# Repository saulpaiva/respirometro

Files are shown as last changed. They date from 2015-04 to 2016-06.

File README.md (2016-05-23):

# **RESPIRÔMETRO**
[Centro de Tecnologia Acadêmica - UFRGS](http://cta.if.ufrgs.br)

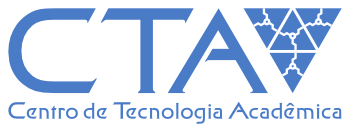
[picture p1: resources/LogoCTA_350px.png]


**Autor/es:** Béuren Felipe Bechlin

**Licença/s:** GPL v3

---
## Descriçao do projeto

O Respirômetro é um equipamento desenhado para medir a frequência respiratória humana. 
Utilizando um par de termistores, o sinal analógico da respiração é convertido em sinal 
digital que pode então ser processado por um microcontrolador que envia dados para o computador.

---
## Primeiros passos

Para utilização do projeto é necessário uma placa de prototipagem Arduino ou um microcontrolador
ATMEGA com suporte a wiring. Na pasta sources você irá encontrar a pasta Arduino que contém o código
fonte deve estar no microcontrolador, já na pasta python contém os códigos fontes para coleta de dados
que são enviados ao computador via comunicação serial gerando um arquivo de log. Nessa mesma pasta
se encontra o arquivo para análise dos dados que foram salvas com a etapa anterior. Lembrando que os
códigos foram desenvolvidos usando *Python* e para seu funcionando é necessário ter instalado o 
interpretador *Python*.
 
### Usando o projeto

#### Passo 1
Primeiro passo a se realizar é instalar as dependências do projeto em sua máquina, caso utiliza
um sistema operacional baseado em GNU/Linux esse trabalho foi reduzido. Supondo que você está
em um ambiente Linux use o seguinte comando:

Esse passo você irá realizar somente uma vez, como é necessário instalar pacotes e módulos python
em seu computador será necessário a senha de administrador para essas operações.

``` Unix
make setup 
```

Após realizar este comando reinicie seu terminal e então realize o segundo passo.

#### Passo 2
Nessa parte será enviado o software para a placa microcontroladora para isso estamos usando
o framework Platformio, lembrando que o firmware desenvolvido foi feito para microcontroladores
ATMEL como suporte a wiring, como por exemplo Arduinos em geral.

``` Unix
make firmware
```

Ao entrar com esse comando irá se iniciar uma tela para seleção da placa que se está usando, além
da porta usb em que ela está conectada ao computador. Na primeira vez que for enviar o firmaware para
cada tipo de placa será necessário digiar _y_ no terminal para que o platformio instale as dependências
para compilação de cada modelo de placa.

---
Para demais informações e documentação completa visite
[CTA - RESPIRÔMETRO](http://cta.if.ufrgs.br/projects/fisiolog/wiki/Respirômetro)

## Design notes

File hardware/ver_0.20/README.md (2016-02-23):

# Respirômetro

Documentação referente a placa de circuito impresso versão 0.2.
Versão em dosenvolvimento.

### Resitores(ohm):
* R1 (6) = 7.3k 
* R2 (4) = 10k
* R3 (2) = 100k
* R4 (2) = 2.2k
* R5 (0) = 3.3k (SD shield)
* R6 (0) = 1.8k (SD shield)
* R7 (3) = 220

### Capacitores:
* C1 (2) = 100 uF 16v

### Cartão SD:

Começando por cima chip conectando para a esquerda, ou o NC(não conectado).

1. NC
2. CS/SS
3. MOSI	= 11 Pin
4. GND
5. NC
6. 3.3v
7. SCK/CLK	= 13 Pin
8. GND
9. MISO 	= 12 Pin
10. NC
11. NC

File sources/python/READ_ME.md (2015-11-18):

# **Respirômetro**

[Centro de Tecnologia Acadêmica - UFRGS](http://cta.if.ufrgs.br)

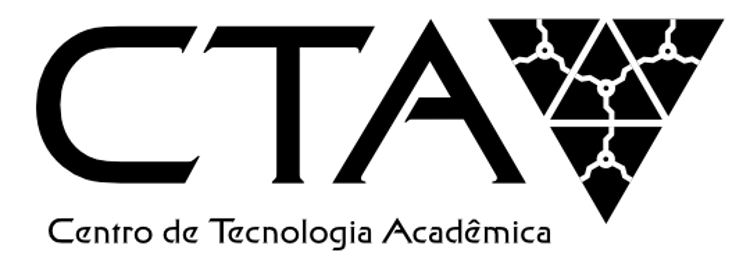
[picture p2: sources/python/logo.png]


**Autor:** Béuren F. Bechlin

**Licença:** GPL v3

---

## Descrição do projeto

O projeto visa criar um equipamento open source que procura inferir a frequência
respirátoria de um indíviduo de forma não invasiva, dimunuindo incômodo como
também possibilitando maiores formas. 

---

## Documentação de uso

### Arduino

 Inicialmente é necessário fazer upload do sketch biometrica.ino para seu micro-
controlador arduino.

### Python

Para o perfeito funcionamento dos algoritmos é necessário ter um interpretador
de python com pelo menos a versão 2.7 instalada em sua máquina. Além disso,
alguns módulos de python são necessários:

* python-scipy
* python-tk (tkInter)
* python-matplotlib
* python-serial

```
sudo apt-get install python-scipy python-tk python-matplotlib python-serial 
```

#### Armazenamento.py

Programa para aquisição dos dados do Arduino salvando-os em um arquivo .log.

Este programa é utilizado com o programa biometrica.ino no qual a taxa de
amostragem é definida no microcontrolador.

Ordem de argumentos : [porta],[taxa_transmissão],[arquivo_saída]
Onde:
1. porta: porta serial no qual o arduino está conectado
2. taxa_transmissão: velocidade de comunicação serial
3. arquivo_saída: nome do arquivo em que os dados serão salvos
4. tempo_de_execução: tempo total de execução, em segundos

PADRÃO NOME DO ARQUIVO DE SAÍDA: coleta_[Nome]_[Sobrenome]_[obs].log
[obs] são observações caso sejam necessárias

Lembrando também que a taxa de transmissão(Baud Rate) da comunicação serial tem
de ser multiplo par de 300. Exemplo 1200, 9600.

#### Visualiza.py

Programa que estima e emite um relatório sobre a frequência respiratória. Lembrando
que quanto menor o tempo amostrado maior a imprecisão do método. Além disso, o tempo
mínimo de amostragem é 5s.

Ordem de argumentos : [arquivo_entrada], [instante inicial], [instante final],
[tipo do filtro], [repetições], [freq_inicial], [freq_final]

Onde:

1. Evidenciando arquivo onde estão os dados a serem anilizado/exibidos:
	1. arquivo_entrada: arquivo que será visualizado/analisado.

2. Determinando em que ponto da amostra quer ser analizado:
	1. instante inicial(s): instante para iniciar a visualização/analise.
	2. instante final(s): instante para finalizar a visualização/analise.

3. Escolhendo filtro apropriado:
	1. tipo do filtro: escolher o filtro a ser utilizado no processo. (1 ou 2)
	2. repetições: definir a quantidade de vezes que o filtro será utilizado.

4. Definindo o espectro de frequência a se uso:
	1. freq_inicial(Hz): definir a frequência inicial positiva que será usada, isso
influenciará na precisão do resultado para o método.
	2. freq_final(Hz): definir a frequência final positiva que será usada, lembrando
que pela definição de transformada de fourier o domínio do espectro de frequência
não será maior que a frequência de obtenção desses dados divido por 2, ou seja,
a as frequências definidas aqui devem estar no intervalo [0;freq/2].

--- 
Para demais informações e documentação completa visite
[CTA - RESPIRÔMETRO](http://cta.if.ufrgs.br/projects/fisiolog/wiki/Respir%C3%B4metro)

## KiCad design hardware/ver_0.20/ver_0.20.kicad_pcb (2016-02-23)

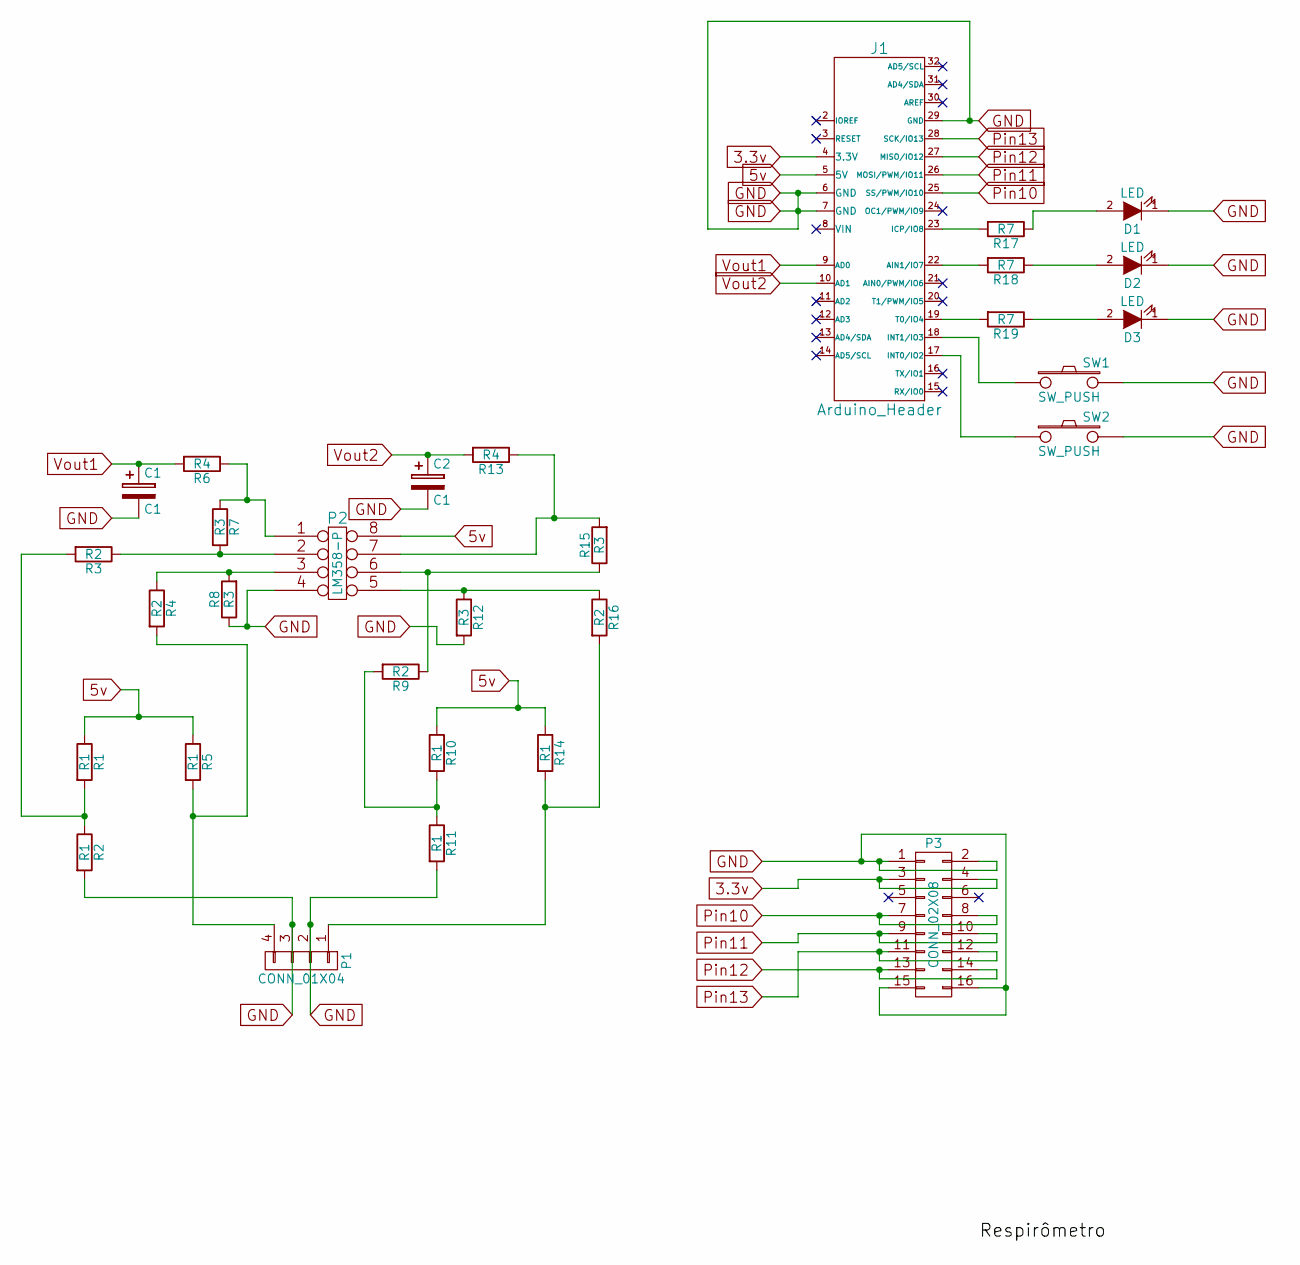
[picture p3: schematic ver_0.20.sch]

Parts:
C1, C2: C1; C2V8
D1, D2, D3: LED; LED-5MM
J1: Arduino_Header; arduino_header
P1: CONN_01X04; Socket_Strip_Straight_1x04
P2: LM358-P; DIP-8_W7.62mm_LongPads
P3: CONN_02X08; Socket_Strip_Straight_2x08
R1, R2, R5, R10, R11, R14: R1; Resistor_Horizontal_RM10mm
R3, R4, R9, R16: R2; Resistor_Horizontal_RM10mm
R6, R13: R4; Resistor_Horizontal_RM10mm
R7, R8, R12, R15: R3; Resistor_Horizontal_RM10mm
R17, R18, R19: R7; Resistor_Horizontal_RM10mm
SW1, SW2: SW_PUSH; SW_PUSH_SMALL

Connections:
3.3v: J1.4 (3.3V), P3.3, P3.4
5v: J1.5 (5V), P2.8, R1.1, R5.1, R10.1, R14.1
GND: C1.2, C2.2, D1.1 (K), D2.1 (K), D3.1 (K), J1.6 (GND), J1.7 (GND), J1.29 (GND), P1.2, P1.3, P2.4, P3.1, P3.2, P3.15, P3.16, R2.2, R8.1, R11.2, R12.2, SW1.2, SW2.2
unnamed: D1.2 (A), R17.1
unnamed: D2.2 (A), R18.1
unnamed: D3.2 (A), R19.1
unnamed: J1.17 (INT0/IO2), SW2.1
unnamed: J1.18 (INT1/IO3), SW1.1
unnamed: J1.19 (T0/IO4), R19.2
unnamed: J1.22 (AIN1/IO7), R18.2
unnamed: J1.23 (ICP/IO8), R17.2
unnamed: P1.1, R14.2, R16.2
unnamed: P1.4, R4.2, R5.2
unnamed: P2.1, R6.1, R7.1
unnamed: P2.2, R3.1, R7.2
unnamed: P2.3, R4.1, R8.2
unnamed: P2.5, R12.1, R16.1
unnamed: P2.6, R9.1, R15.1
unnamed: P2.7, R13.1, R15.2
unnamed: R1.2, R2.1, R3.2
unnamed: R9.2, R10.2, R11.1
Pin10: J1.25 (SS/PWM/IO10), P3.7, P3.8
Pin11: J1.26 (MOSI/PWM/IO11), P3.9, P3.10
Pin12: J1.27 (MISO/IO12), P3.13, P3.14
Pin13: J1.28 (SCK/IO13), P3.11, P3.12
Vout1: C1.1, J1.9 (AD0), R6.2
Vout2: C2.1, J1.10 (AD1), R13.2

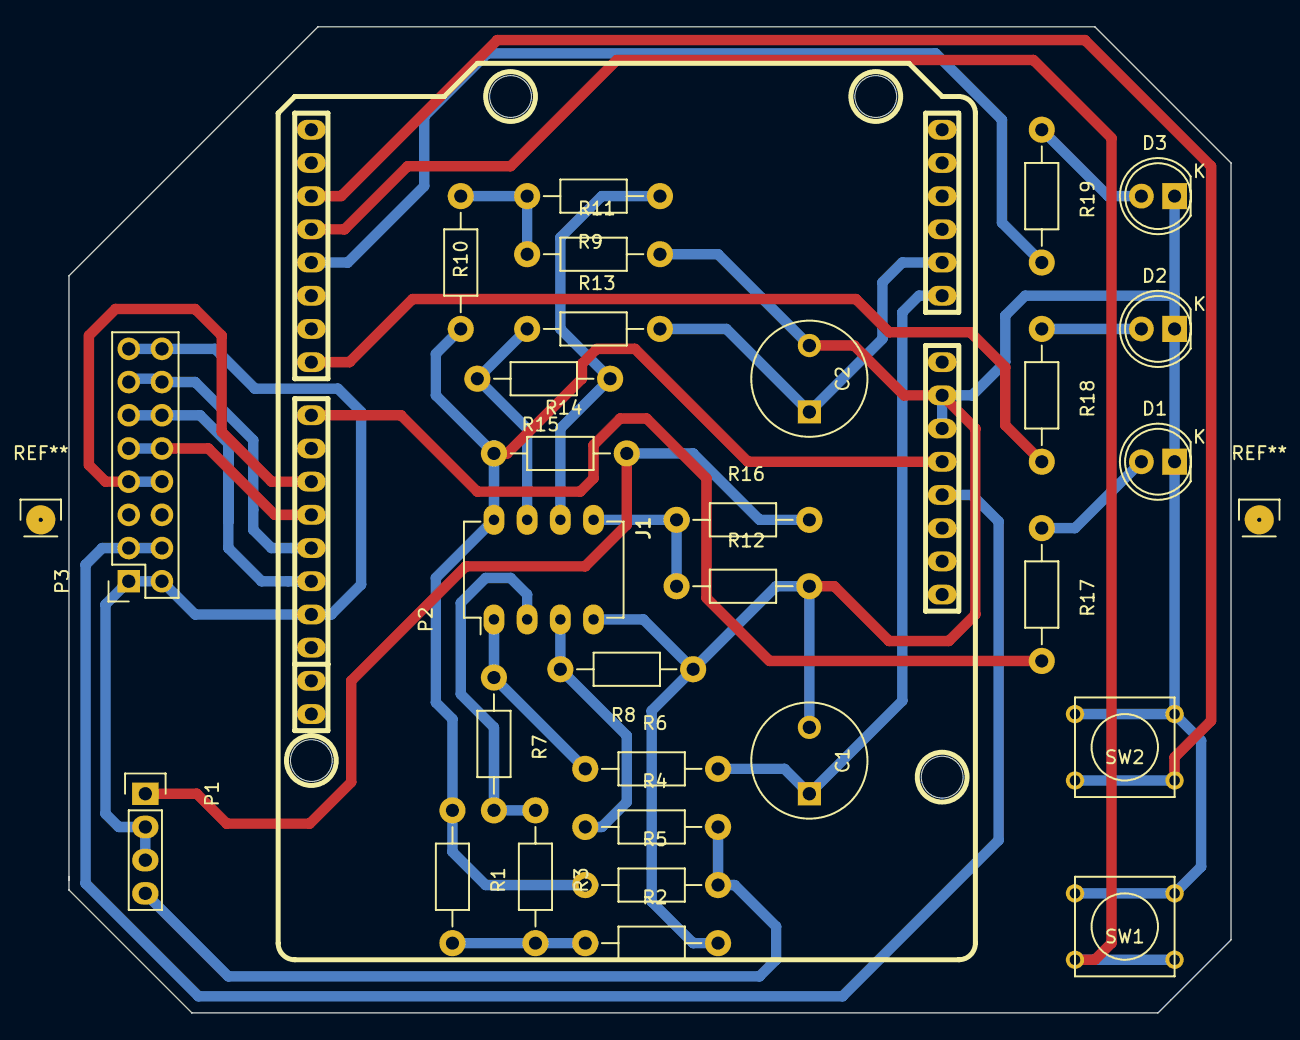
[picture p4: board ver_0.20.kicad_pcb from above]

Board: 2 copper layers, 88.9 x 75.4 mm, 30 parts (0 on the bottom side), 27 nets.

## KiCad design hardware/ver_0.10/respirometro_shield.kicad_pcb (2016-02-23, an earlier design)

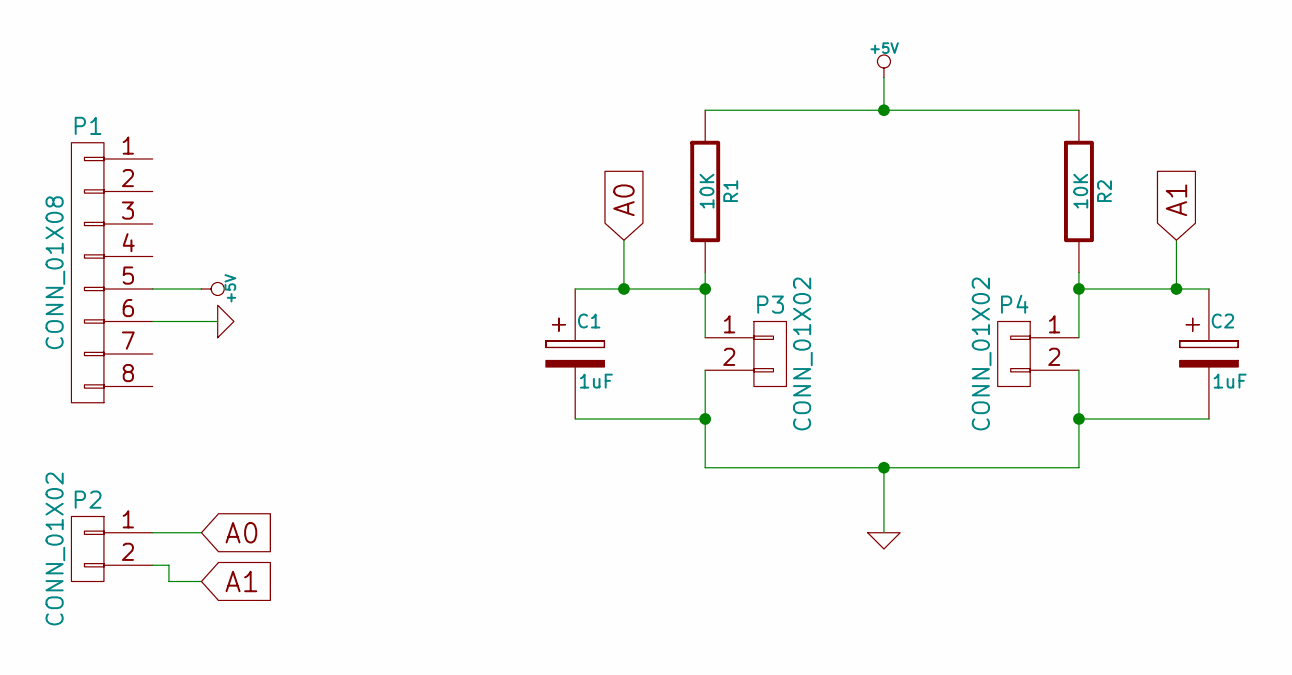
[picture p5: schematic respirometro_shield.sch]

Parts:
C1, C2: 1uF; C_Radial_D5_L11_P2.5
P1: CONN_01X08; PINHEAD1-6
P2, P3, P4: CONN_01X02; PINHEAD1-2
R1: 10K; Resistor_Horizontal_RM10mm
R2: 10K; Resistor_Horizontal_RM15mm

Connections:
+5V: P1.5, R1.1, R2.1
A0: C1.1, P2.1, P3.1, R1.2
A1: C2.1, P2.2, P4.1, R2.2
GND: C1.2, C2.2, P1.6, P3.2, P4.2

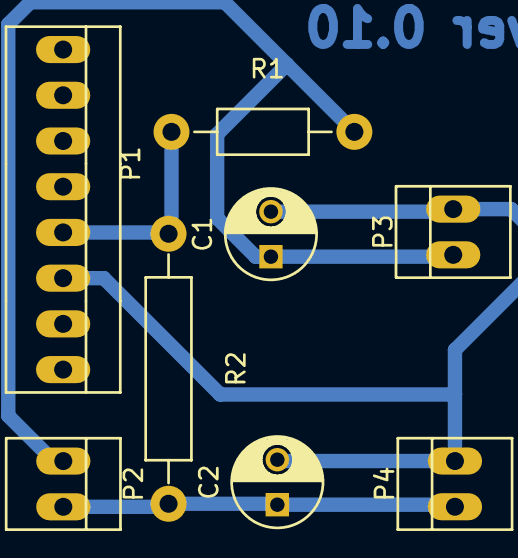
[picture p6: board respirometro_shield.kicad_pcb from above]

Board: 2 copper layers, 8 parts (0 on the bottom side), 4 nets.

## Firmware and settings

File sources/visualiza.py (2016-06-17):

#!/usr/bin/env python
# -*- coding: utf-8 -*-
'''
 Estação biométrica CTA
 Béuren Bechlin

 Programa para estimar a frequência respiratória

 Centro de Tecnologia Acadêmica - UFRGS
 http://cta.if.ufrgs.br

 Licença: GPL v3
 Ordem de argumentos : [arquivo_entrada], [instante inicial], [instante final],
    [tipo do filtro], [repetições], [freq_inicial], [freq_final]
 Onde:

  -Evidenciando arquivo onde estão os dados a serem anilizado/exibidos:
	[arquivo_entrada]: arquivo que será visualizado/analisado.

  -Determinando em que ponto da amostra quer ser analizado:
    [instante inicial](s): instante para iniciar a visualização/analise.
	[instante final](s): instante para finalizar a visualização/analise.

  -Escolhendo filtro apropriado:
    [tipo do filtro]: escolher o filtro a ser utilizado no processo. (1 ou 2)
	[repetições]: definir a quantidade de vezes que o filtro será utilizado.

  -Definindo o espectro de frequência a se uso:
    [freq_inicial](Hz): definir a frequência inicial positiva que será usada, isso
        influenciará na precisão do resultado para o método.
    [freq_final](Hz): definir a frequência final positiva que será usada, lembrando
        que pela definição de transformada de fourier o domínio do espectro de
        frequência não será maior que a frequência de obtenção desses dados
        divido por 2, ou seja, a as frequências definidas aqui devem estar no
        intervalo [0;freq/2]
'''
# Exemplo: python3 visualiza.py coleta_Nome_Exemplo_1min.log 0 60 2 4 0 1
from array import *
from scipy.fftpack import fft, fftfreq, fftshift
import numpy as np
from armazenamento import unpackData, selectDataRange
import sys, os, re, math
import matplotlib.pyplot as plt

# ERROS:
# Testando se contém os argumentos
if len(sys.argv) < 8:
    sys.stderr.write('ERRO: Argumentos insuficientes.\nEm caso de dúvidas leia o READ_ME.md.\n' )
    sys.exit(1)
# Arquivo de dados existe
if not os.path.exists(sys.argv[1]):
	sys.stderr.write('ERRO: Arquivo '+sys.argv[1]+' não encontrado!\nEm caso de dúvidas leia o READ_ME.md.\n')
	sys.exit(1)

# Atribuindo as váriaveis com os valores de entrada
parametro = sys.argv[1:]
log_file = parametro[0]
t_inicial = int(parametro[1])
t_final = int(parametro[2])
n_filtro = int(parametro[3])
qtd_filtro = int(parametro[4])
freq_i = float(parametro[5])
freq_f = float(parametro[6])
user_name = os.path.splitext(os.path.basename(log_file))[0]
png_name = 'Resp_{}_{}s_{}s_{}hz_{}hz.png'.format(user_name, t_inicial, t_final, freq_i, freq_f)

# ERRO:
# Ajustando para que os pontos iniciais não sejam maiores que os finais
if t_inicial > t_final:
	aux_1 = t_inicial
	t_inicial = t_final
	t_final = aux_1

if freq_i > freq_f:
	aux_1 = freq_i
	freq_i = freq_f
	freq_f = aux_1

if t_inicial < 0 or t_final < 0:
	sys.stderr.write('ERRO: Não possível operar com intervalos negativos.\nEm caso de dúvidas leia o READ_ME.md.\n')
	sys.exit(1)

data = unpackData(log_file)
freq = float(data['Freq']) 
N = len(data['A0'])
T = 1.0/freq
dx = float(freq)/N

data = selectDataRange(data, 'Tempo', t_inicial, t_final)

# Inicialização de variáveis
x1 = array('f', data['Tempo'])
y1 = array('f', data['A0'])
y2 = array('f', data['A1'])
y1_filt = array('f', [])
y2_filt = array('f', [])
x_fft_plot = array('f', [])
y1_fft_plot = array('f', [])
y2_fft_plot = array('f', [])
x_fft = array('f', [])
y1_fft = array('f', [])
y2_fft = array('f', [])


med_y1 = 0
med_y2 = 0
var_y1 = 0
var_y2 = 0

N_i = 0
N_f = 0
sum_int_1 = 0
sum_int_2 = 0
sum_norm_1 = 0
sum_norm_2 = 0


# ERROS:
# Tratando N maior que a quantidade de dados contidos no arquivo
# if (i >= cont_ini and i < cont_final) or (i < cont_ini and i < cont_final):
#         sys.stderr.write('ERRO: Intervalo de tempo %i s à %i s não está contido no arquivo.\nArquivo contém o intervalo de tempo: %i s.\nEm caso de dúvidas leia o READ_ME.md.\n' %(t_inicial, t_final, i*T))
#         sys.exit(1)
# Filtro não identificado
if (n_filtro != 1 and n_filtro != 2):
	sys.stderr.write('ERRO: Filtro %i não identificado.\nEm caso de dúvidas leia o READ_ME.md.\n' % n_filtro)
	sys.exit(1)
if (freq_i > float(freq)/2 or freq_f > float(freq)/2):
	sys.stderr.write('ERRO: Intervalo %.2f Hz à %.2f Hz de frequência não é possível de ser implementado.\nFrequência máxima possível para esse arquivo: %.2f Hz.\nEm caso de dúvidas leia o READ_ME.md.\n' %(freq_i, freq_f, float(freq)/2))
	sys.exit(1)
if (freq_f - freq_i < 0.1 ):
	sys.stderr.write('ERRO: Não é possível ter essa resolução do domínio frequência.\nEm caso de dúvidas leia o READ_ME.md.\n')
	sys.exit(1)
if (freq_i < 0 or freq_f < 0):
	sys.stderr.write('ERRO: Não possível operar com frequências negativas.\nLembrando que o espectro de frequência é uma função par, Y(f)= Y(-f).\nEm caso de dúvidas leia o READ_ME.md.\n')
	sys.exit(1)

# Média e varianca:
med_y1 = sum(y1) / len(y1)
med_y2 = sum(y2) / len(y2)
maior_abs_y1 = med_y1 - (max(y1) if max(y1) + min(y1) > 2*med_y1 else min(y1))
maior_abs_y2 = med_y2 - (max(y2) if max(y2) + min(y2) > 2*med_y2 else min(y2))
for j in range(0, len(y1)):
	y1[j] = (y1[j] - med_y1)/maior_abs_y1
	y2[j] = (y2[j] - med_y2)/maior_abs_y2
	# Desvio:
	var_y1 += y1[j] * y1[j]
	var_y2 += y2[j] * y2[j]
	y1_filt.append(y1[j])
	y2_filt.append(y2[j])

var_y1 /= len(y1)
var_y2 /= len(y2)
var_med = (var_y1 + var_y2)/2
des_y1 = var_y1**(0.5)
des_y2 = var_y2**(0.5)
des_med = (var_med)**(0.5)

# Filtro:
if(n_filtro == 1):
    for n in range(1,qtd_filtro):
        for k in xrange(1, len(y1) - 2):
            y1_filt[k] = (y1_filt[k-1] + y1_filt[k] + y1_filt[k+1])/3
            y2_filt[k] = (y2_filt[k-1] + y2_filt[k] + y2_filt[k+1])/3
elif(n_filtro == 2):
    for n in range(1,qtd_filtro):
        y1_filt[1] = (y1_filt[0] + y1_filt[1] + y1_filt[2])/3
        y2_filt[1] = (y2_filt[0] + y2_filt[1] + y2_filt[2])/3
    for k in range(2, len(y1) - 3):
        y1_filt[k] = (y1_filt[k-2] + y1_filt[k-1] + y1_filt[k] + y1_filt[k+1] + y1_filt[k+2])/5
        y2_filt[k] = (y2_filt[k-2] + y2_filt[k-1] + y2_filt[k] + y2_filt[k+1] + y2_filt[k+2])/5
        y1_filt[len(y1) - 2] = (y1_filt[len(y1) - 3] + y1_filt[len(y1) - 2] + y1_filt[len(y1)-1])/3
        y2_filt[len(y2) - 2] = (y2_filt[len(y2) - 3] + y2_filt[len(y2) - 2] + y2_filt[len(y2)-1])/3

# Transformada de fourier:
#   yn_fft x_fft: realizam a trasnformada de fourier no espectro de frequência
#   yn_fft_plot x_fft_plot: inicialmente é usado um 'shift'(deslocamento) para jogar as
#       componentes negativas que estão após as componentes positivas quando usamos
#       numpy.fft.fftshift, para o início do array.
#   yn_fft_plot x_fft_plot: são usados novamente para agora selecionar somente as frequências
#       positivas e suas componentes

y1_fft = fft(y1_filt)
y2_fft = fft(y2_filt)
x_fft = fftfreq(N, T)
x_fft_plot = fftshift(x_fft)
x_fft_plot = x_fft_plot[N/2:N]
y1_fft_plot = fftshift(y1_fft)
y2_fft_plot = fftshift(y2_fft)
y1_fft_plot = np.abs(y1_fft_plot[N/2:N])
y2_fft_plot = np.abs(y2_fft_plot[N/2:N])


# Transformada de fourier na metade de todo período:
N_half = int(N/2)
t_half = float(t_final + t_inicial)/2

x_half_fft = fftfreq(N_half, T)
x_half_fft = fftshift(x_half_fft)
x_half_fft = x_half_fft[math.floor(N_half/2):N_half]


y1_half_1_fft = fft(y1_filt[0:N_half])
y2_half_1_fft = fft(y2_filt[0:N_half])

y1_half_1_fft = fftshift(y1_half_1_fft)
y2_half_1_fft = fftshift(y2_half_1_fft)

y1_half_1_fft = np.abs(y1_half_1_fft[math.floor(N_half/2):N_half])
y2_half_1_fft = np.abs(y2_half_1_fft[math.floor(N_half/2):N_half])


y1_half_2_fft = fft(y1_filt[N_half:N])
y2_half_2_fft = fft(y2_filt[N_half:N])

y1_half_2_fft = fftshift(y1_half_2_fft)
y2_half_2_fft = fftshift(y2_half_2_fft)

y1_half_2_fft = np.abs(y1_half_2_fft[math.floor(N_half/2):N_half])
y2_half_2_fft = np.abs(y2_half_2_fft[math.floor(N_half/2):N_half])

# MATH.FLOOR para conter o 0
# Determinando momento das distribuições:
#   N através da frequência já que também depende da frequência, N = tempo da amostra*freq
#       dessa forma as razões entre eles são constantes
#   N/F = F.tempo/F = tempo -> N'/F' = N/F

N_i = freq_i*N/freq
N_f = freq_f*N/freq

for i in range(int(N_i),int(N_f)):
	aux_1 = y1_fft_plot[i]*y1_fft_plot[i]*y1_fft_plot[i]*dx
	aux_2 = y2_fft_plot[i]*y2_fft_plot[i]*y2_fft_plot[i]*dx

	sum_int_1 += aux_1*x_fft_plot[i]
	sum_int_2 += aux_2*x_fft_plot[i]

	sum_norm_1 += aux_1
	sum_norm_2 += aux_2

first_moment_1 = sum_int_1 / sum_norm_1
first_moment_2 = sum_int_2 / sum_norm_2
first_moment_med = (first_moment_1 + first_moment_2)/2
t_est_1 = 1.0/first_moment_1
t_est_2 = 1.0/first_moment_2
t_est_med = 1.0/first_moment_med

N_i = freq_i*N_half/freq
N_f = freq_f*N_half/freq

sum_int_1 = 0
sum_int_2 = 0
sum_norm_1 = 0
sum_norm_2 = 0

for i in range(int(N_i),int(N_f)):
	aux_1 = y1_half_1_fft[i]*y1_half_1_fft[i]*y1_half_1_fft[i]*dx
	aux_2 = y2_half_1_fft[i]*y2_half_1_fft[i]*y2_half_1_fft[i]*dx

	sum_int_1 += aux_1*x_half_fft[i]
	sum_int_2 += aux_2*x_half_fft[i]

	sum_norm_1 += aux_1
	sum_norm_2 += aux_2

first_moment_1_half_1 = sum_int_1 / sum_norm_1
first_moment_2_half_1 = sum_int_2 / sum_norm_2
first_moment_med_half_1 = (first_moment_1_half_1 + first_moment_2_half_1)/2
t_est_1_half_1 = 1.0/first_moment_1_half_1
t_est_2_half_1 = 1.0/first_moment_2_half_1
t_est_med_half_1 = 1.0/first_moment_med_half_1

sum_int_1 = 0
sum_int_2 = 0
sum_norm_1 = 0
sum_norm_2 = 0

for i in range(int(N_i),int(N_f)):
	aux_1 = y1_half_2_fft[i]*y1_half_2_fft[i]*y1_half_2_fft[i]*dx
	aux_2 = y2_half_2_fft[i]*y2_half_2_fft[i]*y2_half_2_fft[i]*dx

	sum_int_1 += aux_1*x_half_fft[i]
	sum_int_2 += aux_2*x_half_fft[i]

	sum_norm_1 += aux_1
	sum_norm_2 += aux_2

first_moment_1_half_2 = sum_int_1 / sum_norm_1
first_moment_2_half_2 = sum_int_2 / sum_norm_2
first_moment_med_half_2 = (first_moment_1_half_2 + first_moment_2_half_2)/2
t_est_1_half_2 = 1.0/first_moment_1_half_2
t_est_2_half_2 = 1.0/first_moment_2_half_2
t_est_med_half_2 = 1.0/first_moment_med_half_2

# Configuração plot
# h1 = fonts[0], h2 ...
fontsize = [20, 18 ,16, 14, 12]
color = ['Blue', 'Green', 'Yellow', 'Red']

# Criando figura do tamanho A4
plt.figure(1, figsize=(8.27, 11.7))
fig = plt.gcf()
fig.canvas.set_window_title('Frequência Respiratória[CTA]\tN1:{}, N2:{}'.format(first_moment_1, first_moment_2))
fig.suptitle('Frequência Respiratória:\n',
        fontsize=fontsize[2],
        fontweight='bold')

sub_plot1 = plt.subplot(3,1,1)
plt.text(0, 1.1, 'Nome: {}                        Data da coleta: {}'.format(user_name, data['Date']),
        horizontalalignment='left',
        fontsize=fontsize[3],
        transform = sub_plot1.transAxes)
plt.text(0, 1.01, 'Horário da Coleta: {}               Tempo analisado {} s à {} s'.format(data['Hour'], str(t_inicial), str(t_final)),
        horizontalalignment='left',
        fontsize=fontsize[3],
        transform = sub_plot1.transAxes)
plt.ylim(-1,1)
plt.plot(x1,y1_filt,
        label = 'Narina Direita',
        color = color[0])
plt.plot(x1,y2_filt,
        label = 'Narina Esquerda',
        color = color[1])
plt.ylabel('Tensão Normalizada y(t)',
        fontsize = fontsize[4])
plt.xlabel('Tempo t(s)',
        fontsize = fontsize[4])
plt.grid(True)

sub_plot2 = plt.subplot(3,1,2)

plt.xlim(freq_i, freq_f)
plt.plot(x_fft_plot,  (1.0/N)*y1_fft_plot,
        label = 'Narina Direita',
        color = color[0])
plt.plot(x_fft_plot,  (1.0/N)*y2_fft_plot,
        label = 'Narina Esquerda',
        color = color[1])
plt.ylabel('|Y(f)|',
        fontsize = fontsize[4])
plt.xlabel('Frequência f(Hz)',
        fontsize = fontsize[4])
sub_plot2.legend(loc='upper right',
        fancybox=True,
        framealpha=0.5)
plt.grid(True)

sub_plot3 = plt.subplot(3,1,3)
sub_plot3.patch.set_visible(False)
sub_plot3.axis('off')

# Item Resultados:
plt.text(0,0.9,'Resultados: \n', fontsize=fontsize[0], fontweight='bold')
plt.text(0,0.84,'   Relativo ao intervalo de {:.2f} segundos à {:.2f} segundos: \n'.format(t_inicial, t_final), fontsize=fontsize[4], fontweight='bold')
plt.text(0,0.78,'          Narina direita:', fontsize=fontsize[4], fontweight='bold')
plt.text(0.4,0.70,'{:.4f}            {:.3f}            {:.3f}          {:.3f}\n'.format(first_moment_1, t_est_1, var_y1, des_y1), fontsize=fontsize[4])
plt.text(0,0.72,'          Narina esquerda:', fontsize=fontsize[4], fontweight='bold')
plt.text(0.4,0.64,'{:.4f}            {:.3f}            {:.3f}          {:.3f}\n'.format(first_moment_2, t_est_2, var_y2, des_y2), fontsize=fontsize[4])
plt.text(0,0.66,'          Média total:', fontsize=fontsize[4], fontweight='bold')
plt.text(0.4,0.58,'{:.4f}            {:.3f}            {:.3f}          {:.3f}\n'.format(first_moment_med, t_est_med, var_med, des_med), fontsize=fontsize[4])
plt.text(0.38,0.58,'Frequência       Período        Variância       Desvio', fontsize=fontsize[4], fontstyle = 'italic')
plt.text(0.42,0.52,'(Hz)                (s)                                  Padrão', fontsize=fontsize[4], fontstyle = 'italic')

plt.text(0,0.38,'   Relativo ao intervalo: \n', fontsize=fontsize[4], fontweight='bold')
plt.text(0.40,0.38,'{:.4f} s a {:.2f} s            {:.2f} s a {:.2f} s'.format(t_inicial, t_half, t_half, t_final), fontsize=fontsize[4], fontweight='bold')
plt.text(0,0.32,'          Narina direita:', fontsize=fontsize[4], fontweight='bold')
plt.text(0.4,0.24,'{:.4f}            {:.3f}            {:.3f}          {:.3f}\n'.format(first_moment_1_half_1, t_est_1_half_1, first_moment_1_half_2, t_est_1_half_2), fontsize=fontsize[4])
plt.text(0,0.26,'          Narina esquerda:', fontsize=fontsize[4], fontweight='bold')
plt.text(0.4,0.18,'{:.3f}            {:.3f}            {:.3f}          {:.3f}\n'.format(first_moment_2_half_1, t_est_2_half_1, first_moment_2_half_2, t_est_2_half_2), fontsize=fontsize[4])
plt.text(0,0.20,'          Média total:', fontsize=fontsize[4], fontweight='bold')
plt.text(0.4,0.12,'{:.4f}            {:.3f}            {:.3f}          {:.3f}\n'.format(first_moment_med_half_1, t_est_med_half_1, first_moment_med_half_2, t_est_med_half_2), fontsize=fontsize[4])
plt.text(0.38,0.12,'Frequência       Período        Frequência       Período', fontsize=fontsize[4], fontstyle = 'italic')
plt.text(0.42,0.06,'(Hz)                (s)                   (Hz)                (s)', fontsize=fontsize[4], fontstyle = 'italic')

plt.subplots_adjust(left = 0.1 ,right = 0.9 ,bottom=0.1, top = 0.9 ,wspace = 0.3, hspace = 0.3)

aux_str = parametro[0]
local_dir = ''
while True:
    reg_exp = re.search('\/', aux_str)
    if reg_exp != None:
        local_dir += aux_str[:reg_exp.start()]
        aux_str = aux_str[reg_exp.end():]
    else:
        break
local_dir += '/' + png_name
fig.savefig(local_dir, dpi=400)
#plt.show()

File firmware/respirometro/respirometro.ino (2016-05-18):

/*
**********************************************************
*                  RESPIRÔMETRO - CTA                    *
**********************************************************
    AUTOR: Béuren F. Bechlin

       +-------------------------------------------+
       |   Centro de Tecnologia Acadêmica - UFRGS  |
       |         http://cta.if.ufrgs.br            |
       +-------------------------------------------+

    Este arquivo fonte faz parte do Respirômetro e está
sobre a licença GPL v3, como também os arquivos:
    * binaryCommunication(.h/.cpp): usado para criar uma
        comunicação com dados binários entre o arduino e 
        o computador e não com CHARS como é o default.
    * utils(.h/.cpp): usado para criar rotinas que devem
        ser executadas com uma frequência fixa, funciona-
        mento análogo com o delay() disponibilizado pela
        plataforma, entretanto não para o processamento
        e sim utiliza metodo de polling para verificar 
        se deve executar algo.

    ENTRADAS ANALÓGICAS:
        A0 :: RESPIRÔMETRO PRIMEIRA ENTRADA
        A1 :: RESPIRÔMETRO SEGUNDA ENTRADA
        A5 :: ELETROCARDIOGRAMA
*/

#include "binaryCommunication.h"
#include "utils.h"

/* Definindo a frequencia de operação do equipamento*/
#define FREQUENCY 250  // Hz

#define CARDIO_PIN A5
#define RESP_PIN_1 A0
#define RESP_PIN_2 A1

/* Criando estruturas de dados para definir como será enviado os 
    dados de comunicação*/
struct{
    byte controlFlag01 = 0xAA;
    byte controlFlag02 = 0xAA; 
    short int frequency = FREQUENCY;;
}headerStruct;

struct{
    short int reads[3];
}dataStruct;

/* Criando comunicação*/
BinCommunication commHeader(&headerStruct, sizeof(headerStruct));
BinCommunication commData(&dataStruct, sizeof(dataStruct));
/* Criando interface que se repetirá a cada '1.0/FREQUENCY'. Essa 
    interface irá chamar a função 'measures' a cada repetição*/
Interface interface(&measures, 1000.0/FREQUENCY);

void setup(){
    /* Iniciando comunicação serial*/
    Serial.begin(115200);
    commHeader.send();
}

void loop(){
    interface.run();
}

void measures(){ 
    dataStruct.reads[0] = analogRead(CARDIO_PIN);
    dataStruct.reads[1] = analogRead(RESP_PIN_1);    
    dataStruct.reads[2] = analogRead(RESP_PIN_2);
    /* Enviando dados*/
    commData.send();      
}

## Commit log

2014-09-30 Primeira Versão para estudo arduino
2014-09-30 Adição arquivo para estudo sobre comunicação serial
2014-09-30 Primeira Versão para estação biométrica
2014-09-30 Alteraçãoes e adição do arquivo para visualização
2014-10-09 Versão 09/10/2014, ajusteno foco e introdução do reset dos dados
    [visualiza.py]
2014-10-14 Adicionado o estudo do periodo mínimo de operação da visualização
2014-10-16 Armazenamento foi ajustado corrigindo erro de lógica
    [armazenamento.py, visualiza.py]
2015-03-11 Atualizado o protocolo de envio de dados e adicionado a segunda medida
2015-03-11 Adição analise de fourier
2015-03-19 Iniciando filtros de sinal
2015-04-08 Primeira versão do respirômetro com as duas narinas, estimando a frequência respiratória e tendo como saída um arquivo .png também ajustado bug para encontrar a frequência do arduino
    Conflicts:
    python/visualiza_new.py
    [armazenamento.py, visualiza.py]
2015-04-08 VER_0.0.01: onde temos o armazenamento dos dados e o algoritmo para estimar a frequência respiratório com saída em .png
2015-04-14 Resolução de erros quanto a indices dos vetores
2015-04-16 Atualização de pequenos bugs, ainda sendo necessário correção de erro na quantidade de dados
2015-04-17 Adição de tratamento de erros na entrada da visualização
2015-04-27 Ajustado bug na quantidade de argumentos e arrumado o shell script!
2016-02-23 Reorganizando repsitório, adicionando esquemáticos e arquivos para confeccão de uma placa de circuito impresso.
    [respirometro_shield.kicad_pcb, respirometro_shield.sch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]
2016-03-30 Firmware criado para testes e utilidades para a placa versão 0.20
2016-05-16 Criando branch para testes
2016-05-18 MODIFY:storeBinData adicionando coluna de tempo
2016-05-23 Corrigido visualização e alterado README.md
    [armazenamento.py, discreteMath.py, freqAnalysis.py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]
2016-05-30 Script de coleta finalizado.
2016-06-17 ATT: empacotamento e desenpacotamento de dados do respirômetro, read-me com instruções de uso
